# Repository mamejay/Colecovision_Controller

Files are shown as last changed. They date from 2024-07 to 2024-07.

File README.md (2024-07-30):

# Colecovision Controller
Controller for colecovision  

author: Jay Convertino 
  - Modified: Mamejay

date: 2024/07/30

## Changes

- Found original devs board had the fire buttons the wrong way around.  When playing games like Loadrunner, digging holes left and right are the opposite.  This has been corrected
- Also I have included a SMD version for the diodes.  This has not been tested yet so build at your own risk

license: MIT (All files in repo)

## Release Versions
### Current
  - release_v1

### Past
  - none
  
## Requirements
  - KiCad v8

## Building
  - KiCad can generate any gerbers you are looking for.

## Parts list
|  REF  | PART NUMBER | QUANTITY |
|:--- |:--- |:--- |
|D1-D28 |1N914 |28 |
|S1-S18 |Omron B3F-10XX |18 |
|J1 |RB-GEN-5839(cable) |1 |
|H1-H8  |#4 x 5/8" Pan,Sheet |8 |
|NA |SHELL TOP (3D print) |1 |
|NA |SHELL BOT (3D print) |1 |
|NA |NUMPAD (3D print) |12 |
|NA |DPAD (3D print) |1 |
|NA |FIRE BUTTON (3D print) |2 |

## Assembly Tips
  - 3D print using ABS plastic.
    - 100.5% for shell size
    - 100% size for all buttons
  - Single sided PCB
  - Only the smallest diode footprint need to be installed vertically.
  - 8 Screws 
    - 5/8th inch long at most.
    - #4 screw 0.112 inch diameter.
    - Course thread (sheet metal type).
    - Pan Head no larger then 3/16th of an inch.

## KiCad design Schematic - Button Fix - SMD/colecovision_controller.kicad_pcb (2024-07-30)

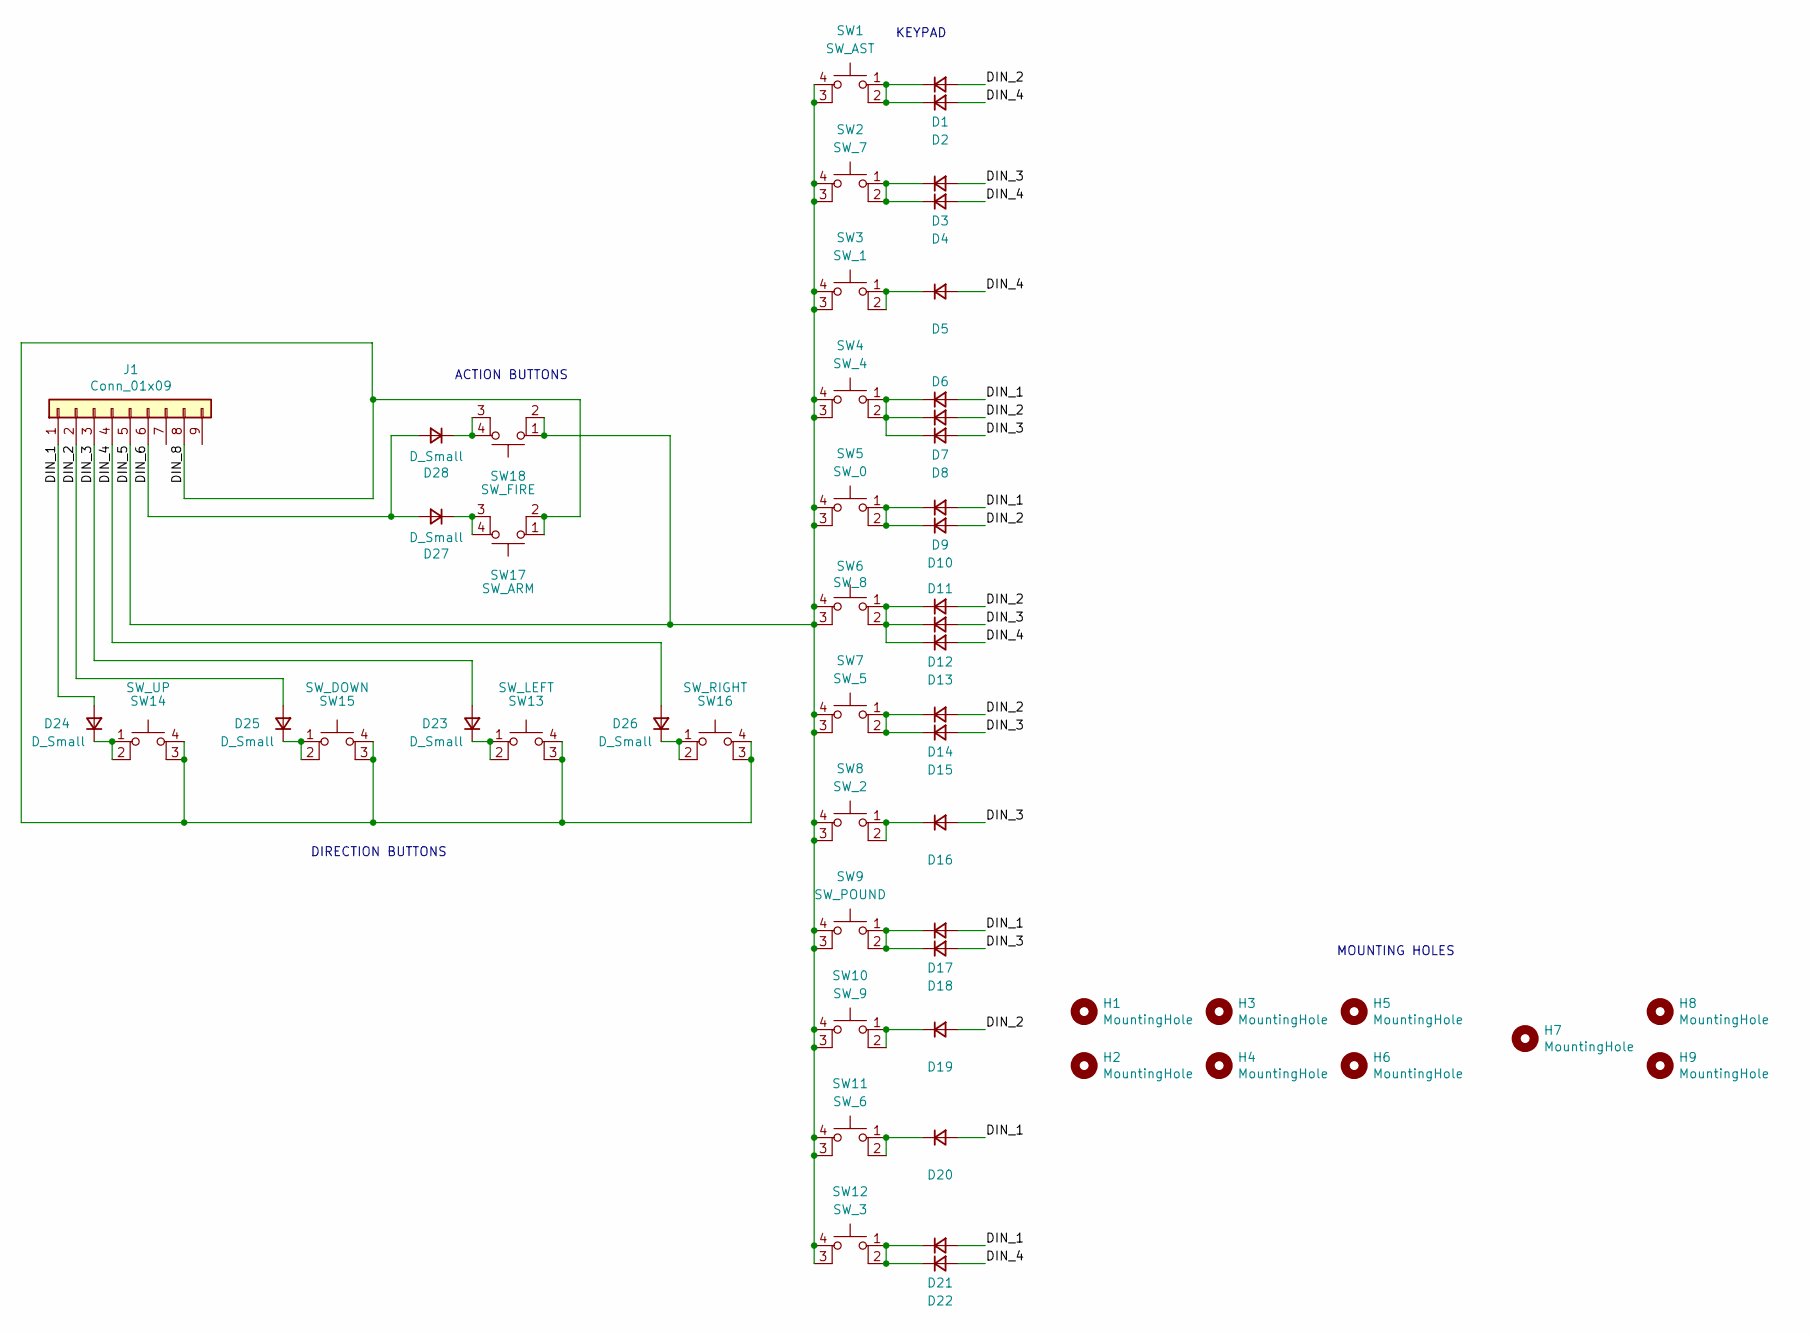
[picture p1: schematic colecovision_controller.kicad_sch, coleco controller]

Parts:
D1, D2, D3, D4, D5, D6, D7, D8, D9, D10, D11, D12, D13, D14, D15, D16, D17, D18, D19, D20, D21, D22, D23, D24, D25, D26, D27, D28: D_Small; D_0805_2012Metric_Pad1.15x1.40mm_HandSolder
H1, H2, H3, H4, H5, H6, H8, H9: MountingHole; MountingHole_4.3mm_M4
H7: MountingHole; MountingHole_2.7mm_M2.5
J1: Conn_01x09; PinSocket_1x09_P2.54mm_Vertical
SW1: SW_AST; SW_TH_Tactile_Omron_B3F-10xx
SW2: SW_7; SW_TH_Tactile_Omron_B3F-10xx
SW3: SW_1; SW_TH_Tactile_Omron_B3F-10xx
SW4: SW_4; SW_TH_Tactile_Omron_B3F-10xx
SW5: SW_0; SW_TH_Tactile_Omron_B3F-10xx
SW6: SW_8; SW_TH_Tactile_Omron_B3F-10xx
SW7: SW_5; SW_TH_Tactile_Omron_B3F-10xx
SW8: SW_2; SW_TH_Tactile_Omron_B3F-10xx
SW9: SW_POUND; SW_TH_Tactile_Omron_B3F-10xx
SW10: SW_9; SW_TH_Tactile_Omron_B3F-10xx
SW11: SW_6; SW_TH_Tactile_Omron_B3F-10xx
SW12: SW_3; SW_TH_Tactile_Omron_B3F-10xx
SW13: SW_LEFT; SW_TH_Tactile_Omron_B3F-10xx
SW14: SW_UP; SW_TH_Tactile_Omron_B3F-10xx
SW15: SW_DOWN; SW_TH_Tactile_Omron_B3F-10xx
SW16: SW_RIGHT; SW_TH_Tactile_Omron_B3F-10xx
SW17: SW_ARM; SW_TH_Tactile_Omron_B3F-10xx
SW18: SW_FIRE; SW_TH_Tactile_Omron_B3F-10xx

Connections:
/DIN_1: D6.2 (A), D9.2 (A), D17.2 (A), D20.2 (A), D21.2 (A), D24.2 (A), J1.1
/DIN_2: D1.2 (A), D7.2 (A), D10.2 (A), D11.2 (A), D14.2 (A), D19.2 (A), D25.2 (A), J1.2
/DIN_3: D3.2 (A), D8.2 (A), D12.2 (A), D15.2 (A), D16.2 (A), D18.2 (A), D23.2 (A), J1.3
/DIN_4: D2.2 (A), D4.2 (A), D5.2 (A), D13.2 (A), D22.2 (A), D26.2 (A), J1.4
/DIN_5: J1.5, SW1.3 (K), SW1.4 (A), SW2.3 (K), SW2.4 (A), SW3.3 (K), SW3.4 (A), SW4.3 (K), SW4.4 (A), SW5.3 (K), SW5.4 (A), SW6.3 (K), SW6.4 (A), SW7.3 (K), SW7.4 (A), SW8.3 (K), SW8.4 (A), SW9.3 (K), SW9.4 (A), SW10.3 (K), SW10.4 (A), SW11.3 (K), SW11.4 (A), SW12.3 (K), SW12.4 (A), SW18.1, SW18.2
/DIN_6: D27.2 (A), D28.2 (A), J1.6
/DIN_8: J1.8, SW13.3 (K), SW13.4 (A), SW14.3 (K), SW14.4 (A), SW15.3 (K), SW15.4 (A), SW16.3 (K), SW16.4 (A), SW17.1, SW17.2
unnamed: D1.1 (K), D2.1 (K), SW1.1, SW1.2
unnamed: D3.1 (K), D4.1 (K), SW2.1, SW2.2
unnamed: D5.1 (K), SW3.1, SW3.2
unnamed: D6.1 (K), D7.1 (K), D8.1 (K), SW4.1, SW4.2
unnamed: D9.1 (K), D10.1 (K), SW5.1, SW5.2
unnamed: D11.1 (K), D12.1 (K), D13.1 (K), SW6.1, SW6.2
unnamed: D14.1 (K), D15.1 (K), SW7.1, SW7.2
unnamed: D16.1 (K), SW8.1, SW8.2
unnamed: D17.1 (K), D18.1 (K), SW9.1, SW9.2
unnamed: D19.1 (K), SW10.1, SW10.2
unnamed: D20.1 (K), SW11.1, SW11.2
unnamed: D21.1 (K), D22.1 (K), SW12.1, SW12.2
unnamed: D23.1 (K), SW13.1, SW13.2
unnamed: D24.1 (K), SW14.1, SW14.2
unnamed: D25.1 (K), SW15.1, SW15.2
unnamed: D26.1 (K), SW16.1, SW16.2
unnamed: D27.1 (K), SW17.3 (K), SW17.4 (A)
unnamed: D28.1 (K), SW18.3 (K), SW18.4 (A)

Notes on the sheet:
KEYPAD
DIRECTION BUTTONS
MOUNTING HOLES
ACTION BUTTONS

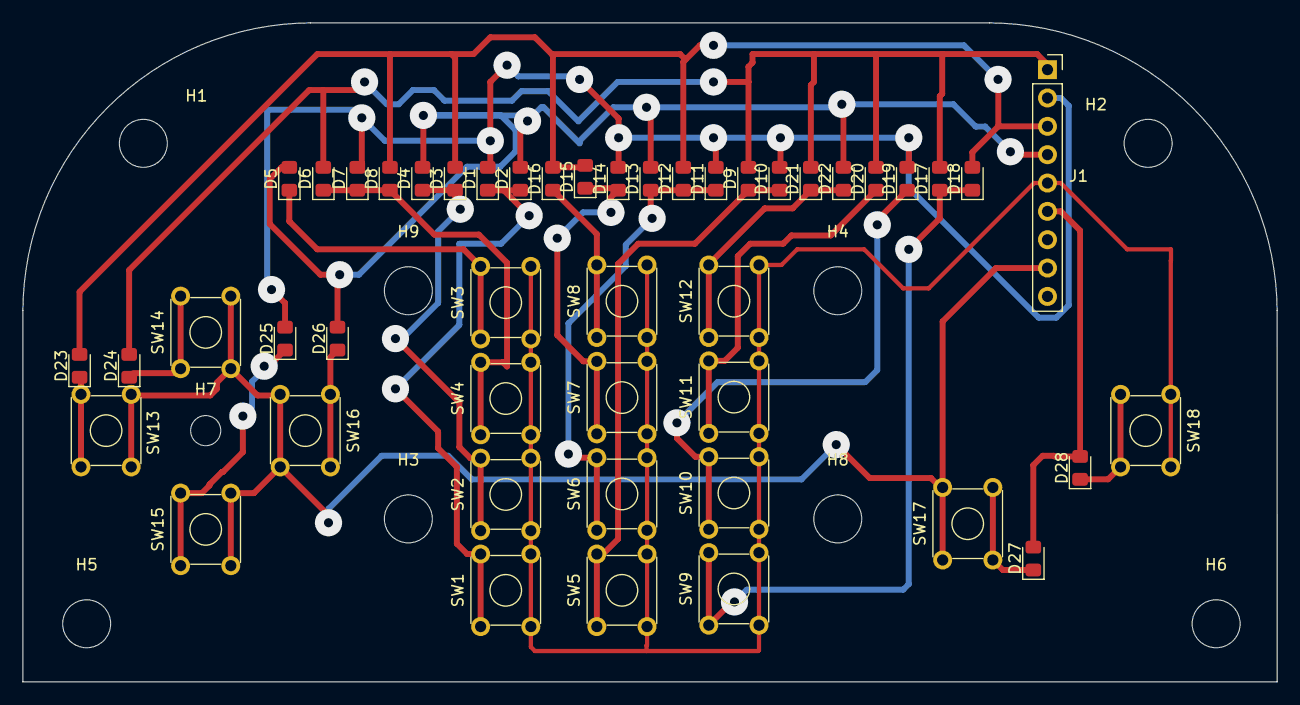
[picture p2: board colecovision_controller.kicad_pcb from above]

Board: 2 copper layers, 112.4 x 59.1 mm, 56 parts (0 on the bottom side), 25 nets.

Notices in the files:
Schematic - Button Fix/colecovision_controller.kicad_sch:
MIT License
